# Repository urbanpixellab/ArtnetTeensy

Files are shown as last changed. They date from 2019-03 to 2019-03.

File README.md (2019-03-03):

# ArtnetTeensy

# Artnet receiver issues by now

testsetup: sending 8 universes all doing the same, turning on one led per frame -> after 150 leds on it restarts.

network issues: 
Wifi: ping ~ 2-4ms , led animation is stotering but all are working
Cabled network: ping ~0.3ms, led animation are not visible, serial print shows only 0-2 universes are received on the teensy

# edit the right etherneth library, i change dthe teensy ethernet library not the arduino

* change the ws5200 size to 8kb incl the mask and change the sockets to one
* and overclock the 3.2 to 96mhz

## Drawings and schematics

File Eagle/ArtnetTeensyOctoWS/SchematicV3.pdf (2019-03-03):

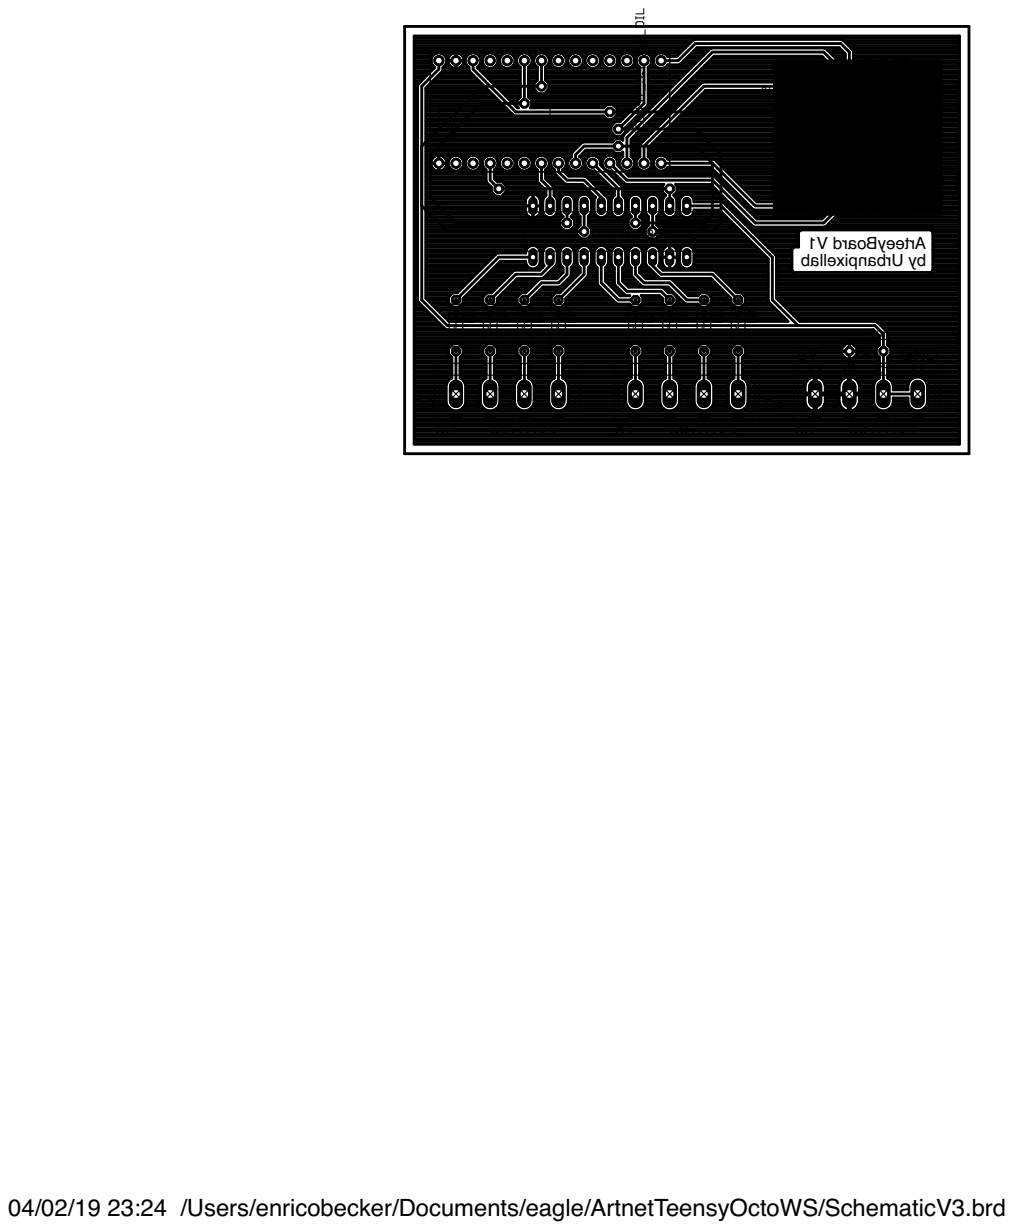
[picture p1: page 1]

04/02/19 23:24 /Users/enricobecker/Documents/eagle/ArtnetTeensyOctoWS/SchematicV3.brd

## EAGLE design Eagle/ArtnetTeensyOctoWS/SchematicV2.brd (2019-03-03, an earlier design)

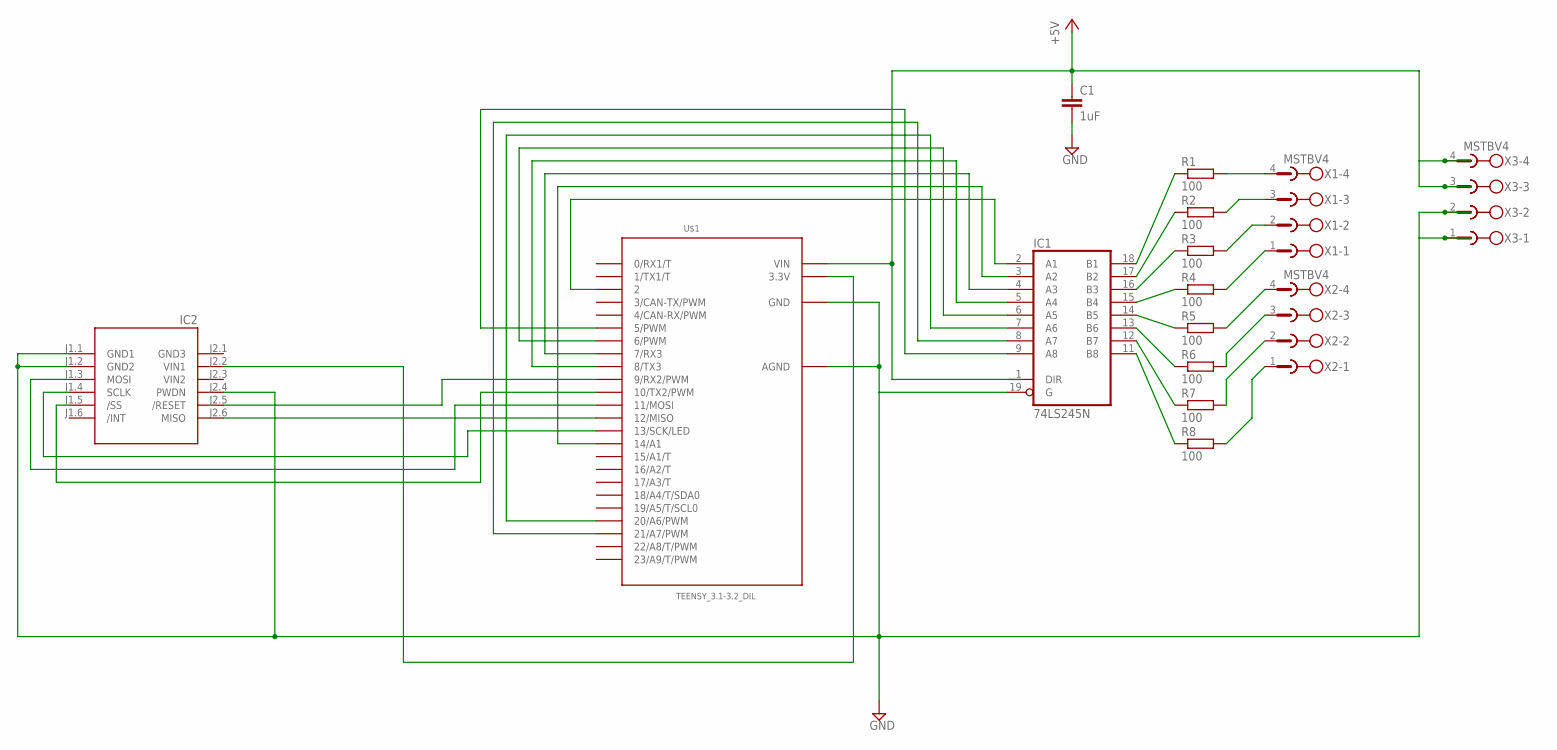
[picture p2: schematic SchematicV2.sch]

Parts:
C1: 1uF; C050-035X075
IC1: 74LS245N; DIL20
IC2: WIZ820IO_DEVICE'DUAL-IN-LINE'; WIZ820IO
R1, R2, R3, R4, R5, R6, R7, R8: 100; 0207/7
U$1: TEENSY_3.1-3.2_DIL; TEENSY_3.0-3.2&LC_DIL
X1, X2, X3: MSTBV4

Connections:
+5V: C1.1, U$1.VIN, X3.3, X3.4
GND: C1.2, IC1.10 (GND), IC1.19 (G), IC2.J1.1 (GND1), IC2.J1.2 (GND2), IC2.J2.4 (PWDN), U$1.AGND, U$1.GND, X3.1, X3.2
GND3: IC2.J2.1 (GND3)
unnamed: IC1.18 (B1), R1.1
unnamed: IC1.17 (B2), R2.1
unnamed: IC1.16 (B3), R3.1
unnamed: IC1.15 (B4), R4.1
unnamed: IC1.14 (B5), R5.1
unnamed: IC1.13 (B6), R6.1
unnamed: IC1.12 (B7), R7.1
unnamed: IC1.11 (B8), R8.1
unnamed: IC1.2 (A1), U$1.2
unnamed: IC1.3 (A2), U$1.14/A0 (14/A1)
unnamed: IC1.4 (A3), U$1.7 (7/RX3)
unnamed: IC1.5 (A4), U$1.8 (8/TX3)
unnamed: IC1.6 (A5), U$1.6 (6/PWM)
unnamed: IC1.7 (A6), U$1.20/A6 (20/A6/PWM)
unnamed: IC1.8 (A7), U$1.21/A7 (21/A7/PWM)
unnamed: IC1.9 (A8), U$1.5 (5/PWM)
unnamed: IC2.J2.2 (VIN1), U$1.3.3V
unnamed: IC2.J2.5 (/RESET), U$1.9 (9/RX2/PWM)
unnamed: IC2.J2.6 (MISO), U$1.12 (12/MISO)
unnamed: IC2.J1.3 (MOSI), U$1.11 (11/MOSI)
unnamed: IC2.J1.4 (SCLK), U$1.13 (13/SCK/LED)
unnamed: IC2.J1.5 (/SS), U$1.10 (10/TX2/PWM)
unnamed: R1.2, X1.4
unnamed: R2.2, X1.3
unnamed: R3.2, X1.2
unnamed: R4.2, X1.1
unnamed: R5.2, X2.4
unnamed: R6.2, X2.3
unnamed: R7.2, X2.2
unnamed: R8.2, X2.1
VCC: IC1.20 (VCC)
VIN2: IC2.J2.3 (VIN2)

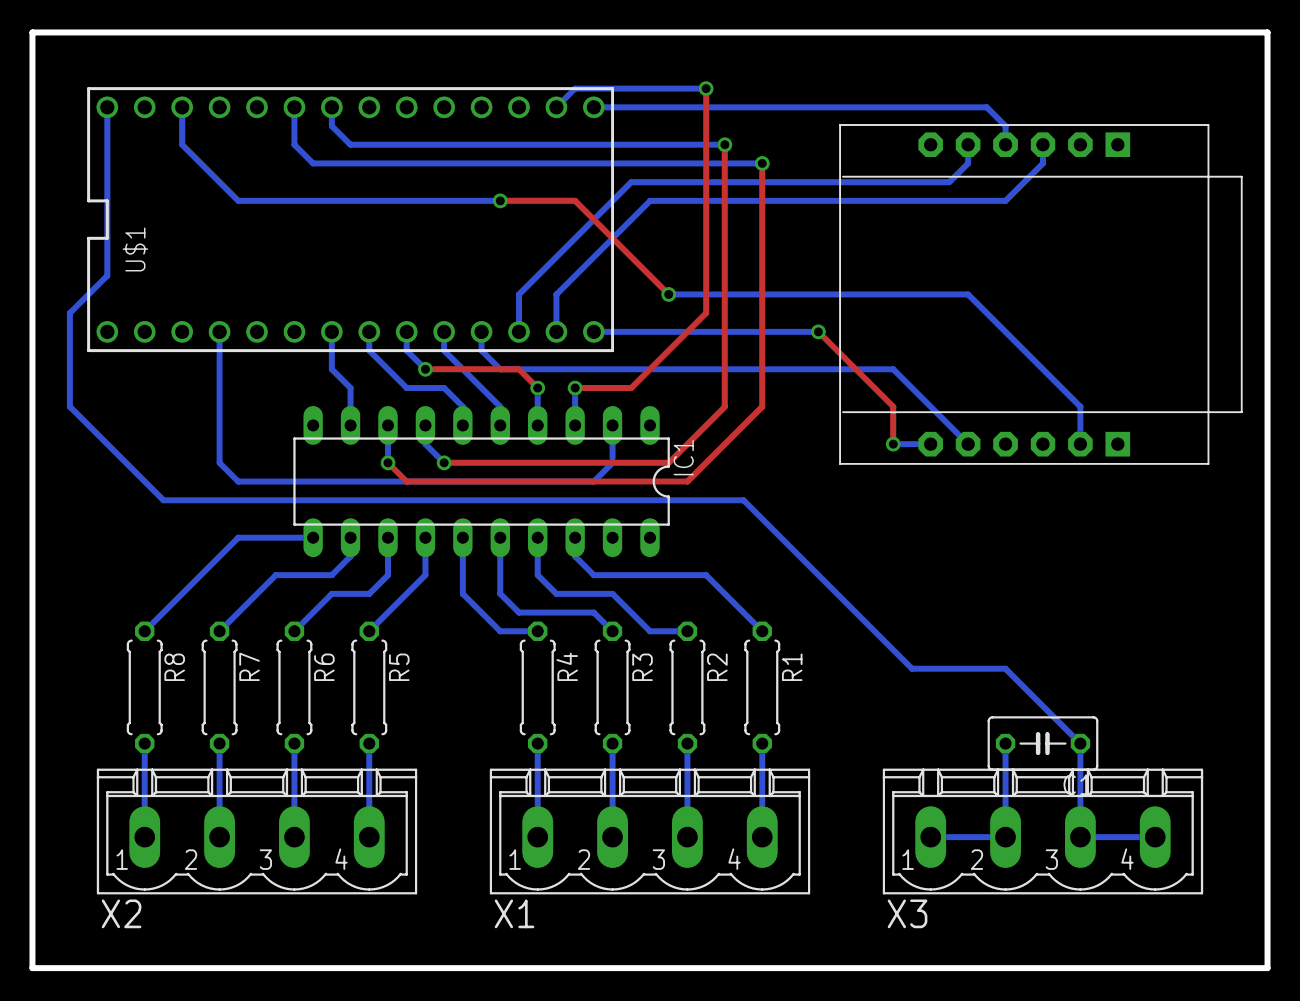
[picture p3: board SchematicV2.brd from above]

Board: 2 copper layers, 83.8 x 63.5 mm, 15 parts (0 on the bottom side), 32 nets.

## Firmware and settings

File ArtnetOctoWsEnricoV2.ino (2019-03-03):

// Receive multiple universes via Artnet and control a strip of ws2811 leds via OctoWS2811
//
// This example may be copied under the terms of the MIT license, see the LICENSE file for details
//  https://github.com/natcl/Artnet
// 
// http://forum.pjrc.com/threads/24688-Artnet-to-OctoWS2811?p=55589&viewfull=1#post55589

#include <Artnet.h>
#include <Ethernet.h>
#include <EthernetUdp.h>
#include <SPI.h>
#include <OctoWS2811.h>

// Ideas for improving performance with WIZ820io / WIZ850io Ethernet:
// https://forum.pjrc.com/threads/45760-E1-31-sACN-Ethernet-DMX-Performance-help-6-Universe-Limit-improvements

// OctoWS2811 settings
//const int ledsPerStrip = 33; // change for your setup
const int ledsPerStrip = 150; // change for your setup
//const byte numStrips= 1; // change for your setup
const byte numStrips= 8; // change for your setup
DMAMEM int displayMemory[ledsPerStrip*6];
int drawingMemory[ledsPerStrip*6];
const int config = WS2811_GRB | WS2811_800kHz;
OctoWS2811 leds(ledsPerStrip, displayMemory, drawingMemory, config);

// Artnet settings
Artnet artnet;
const int startUniverse = 0; // CHANGE FOR YOUR SETUP most software this is 1, some software send out artnet first universe as zero.
const int numberOfChannels = ledsPerStrip * numStrips * 3; // Total number of channels you want to receive (1 led = 3 channels)

byte channelBuffer[numberOfChannels]; // Combined universes into a single array

// Check if we got all universes
const int maxUniverses = numberOfChannels / 450 + ((numberOfChannels % 450) ? 1 : 0);
bool universesReceived[maxUniverses];
bool sendFrame = 1;

// Change ip and mac address for your setup
//byte ip[] = {192, 168, 12, 200};
byte ip[] = {192, 168, 178, 200};
byte mac[] = {0x04, 0xE9, 0xE5, 0x00, 0x69, 0xEC};

void setup()
{
    // Open serial communications and wait for port to open:
  pinMode(9, OUTPUT);
  digitalWrite(9, LOW);    // begin reset the WIZ820io
  pinMode(10, OUTPUT);
  digitalWrite(10, HIGH);  // de-select WIZ820io
  digitalWrite(9, HIGH);   // end reset pulse

  Serial.begin(115200);
  artnet.begin(mac, ip);
  leds.begin();
  initTest();

  // this will be called for each packet received
  artnet.setArtDmxCallback(onDmxFrame);
}

void loop()
{
  // we call the read function inside the loop
  artnet.read();
}

void onDmxFrame(uint16_t universe, uint16_t length, uint8_t sequence, uint8_t* data)
{
  //debug
  //Serial.print("frame ");
  //Serial.print(universe);
  //Serial.print("\t");
  //Serial.println(length);
  //Serial.print(universe);
  
  sendFrame = 1;
  // Store which universe has got in
  if (universe < maxUniverses)
    universesReceived[universe] = 1;

  for (int i = 0 ; i < maxUniverses ; i++)
  {
    if (universesReceived[i] == 0)
    {
      sendFrame = 0;
      break;
    }
  }

  // read universe and put into the right part of the display buffer
  for (int i = 0 ; i < length ; i++)
  {
    int bufferIndex = i + ((universe - startUniverse) * length);
    if (bufferIndex < numberOfChannels) // to verify
      channelBuffer[bufferIndex] = byte(data[i]);
  }      

  // send to leds
  for (int i = 0; i < ledsPerStrip * numStrips; i++)
  {
    leds.setPixel(i, channelBuffer[(i) * 3], channelBuffer[(i * 3) + 1], channelBuffer[(i * 3) + 2]);
  }      
  
  if (sendFrame)
  {
    leds.show();
    memset(universesReceived, 0, maxUniverses);
  }
}

void initTest()
{
  for (int i = 0 ; i < ledsPerStrip * numStrips ; i++)
    leds.setPixel(i, 127, 0, 0);
  leds.show();
  delay(500);
  for (int i = 0 ; i < ledsPerStrip * numStrips  ; i++)
    leds.setPixel(i, 0, 127, 0);
  leds.show();
  delay(500);
  for (int i = 0 ; i < ledsPerStrip * numStrips  ; i++)
    leds.setPixel(i, 0, 0, 127);
  leds.show();
  delay(500);
  for (int i = 0 ; i < ledsPerStrip * numStrips  ; i++)
    leds.setPixel(i, 0, 0, 0);
  leds.show();
}
